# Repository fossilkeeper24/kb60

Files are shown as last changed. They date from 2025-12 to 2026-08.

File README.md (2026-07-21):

# kb60

> just another custom 60% keyboard

I didn't like having a numpad on my keyboard because it just collects dust as I never use the numpad. I also like having super easy to access media control. So I thought yeah why not let's make our own keyboard :3 While having the most minor changes to a 60% ISO layout keyboard, it's different enough to warrant its own project.

## Some pictures

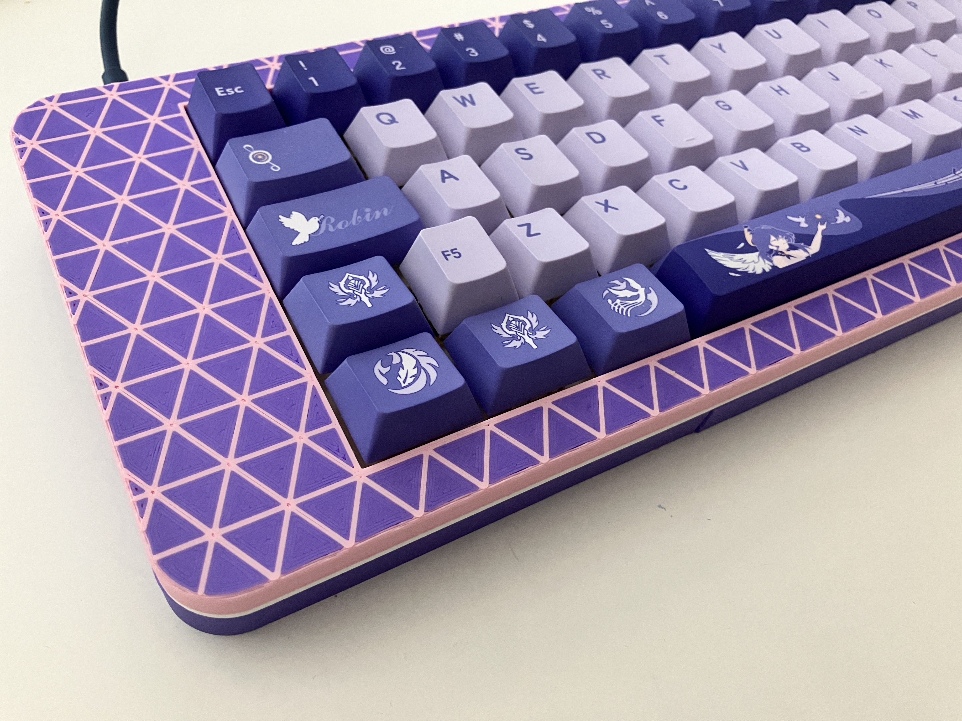
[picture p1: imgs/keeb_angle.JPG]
assembled keyboard


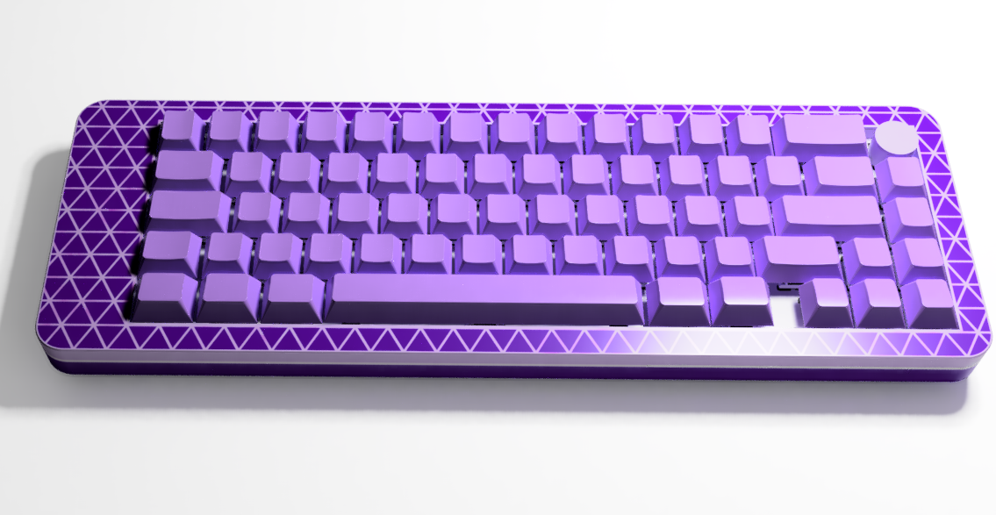
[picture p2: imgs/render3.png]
keyboard case render


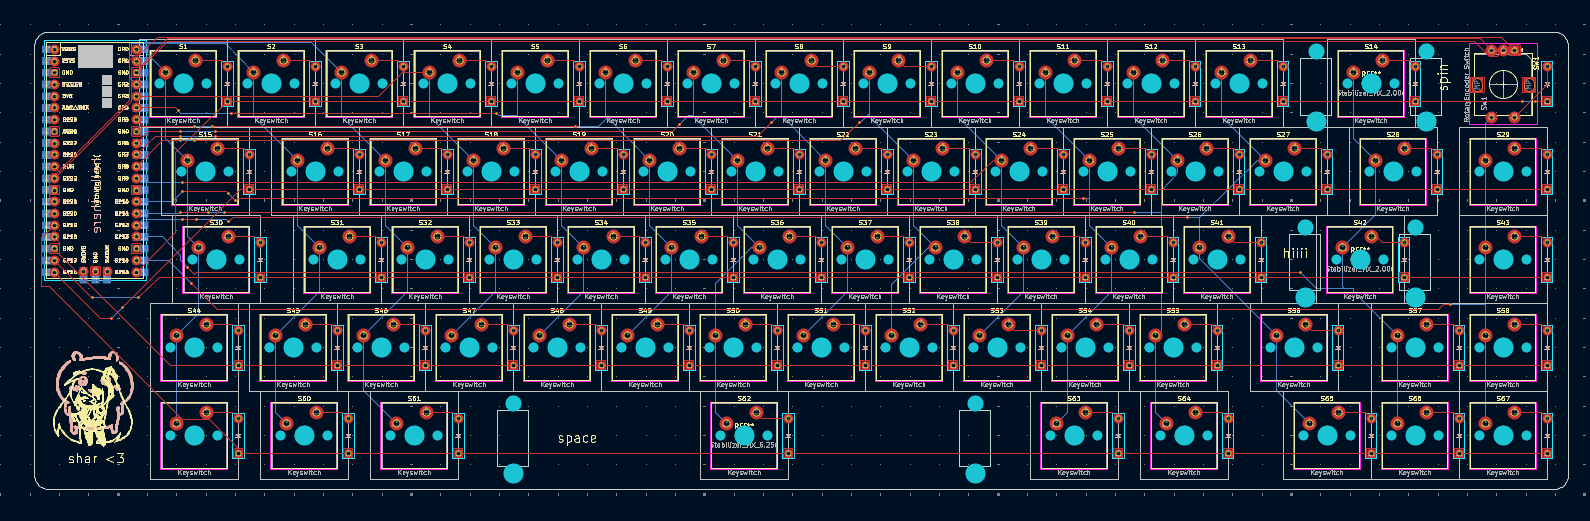
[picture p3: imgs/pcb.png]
pcb


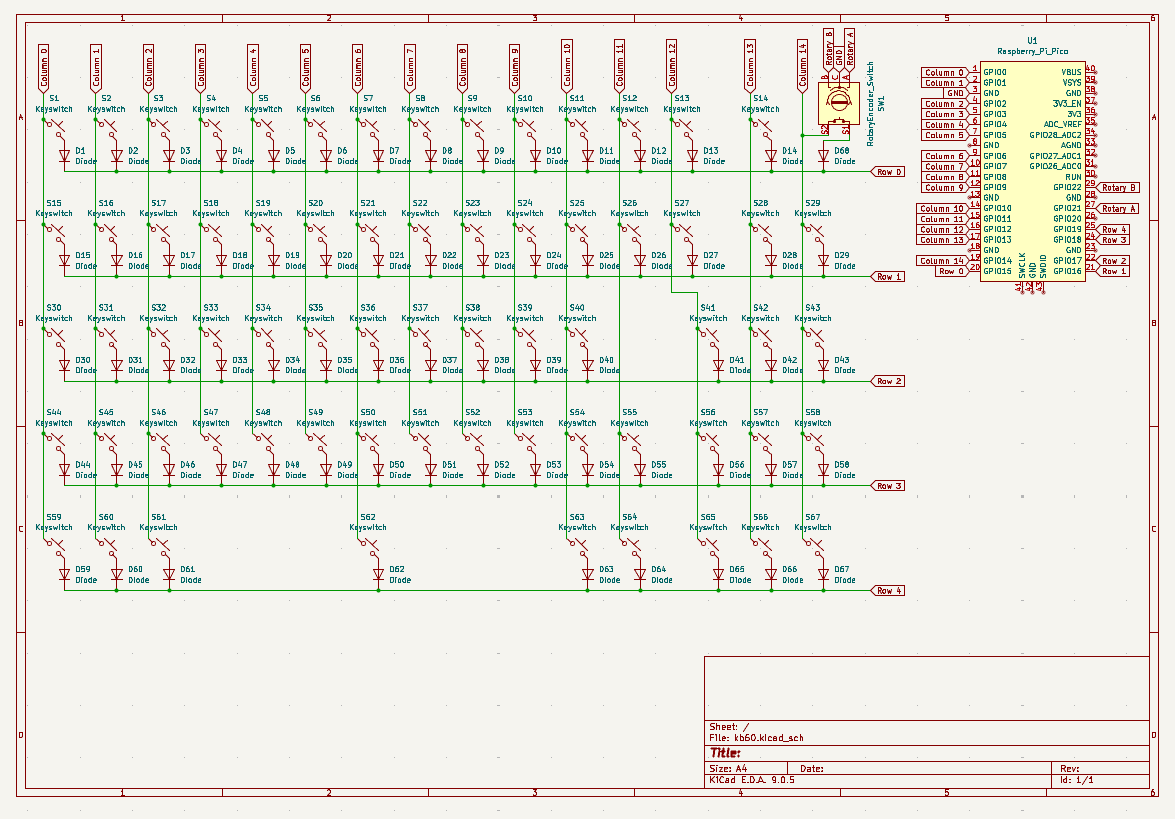
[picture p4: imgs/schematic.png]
schematic


## BOM

|Name |Link |price ($)|Notes |
|---|---|---|---|
|rasp pi pico  |https://www.aliexpress.com/item/1005003753933847.html |2.40 | |
|rotary encoder |https://www.aliexpress.com/item/1005005983134515.html |2.59 | 15mm length |
|stabilizers |https://www.aliexpress.com/item/1005001632672798.html |17.89 |choose ones that go with whatever switches i choose|
|switches |https://www.aliexpress.com/item/1005007665996795.html |14.68*2 | |
|diodes |https://www.aliexpress.com/item/2025724181.html|1.91 | |
|keycaps |https://www.aliexpress.com/item/1005008714429564.html |33.30 |142 keys |
|m3x12 screws  |https://www.aliexpress.com/item/32510989714.html |1.58 | |
|m3 heatset |https://www.aliexpress.com/item/1005006838108683.html |1.99 |L4 4.2mm |
|PLA |print legion goats | | |
|PCB |JLC PCB |31.85 |there are many coupons that i could use |
|TOTAL | |122.87 | |

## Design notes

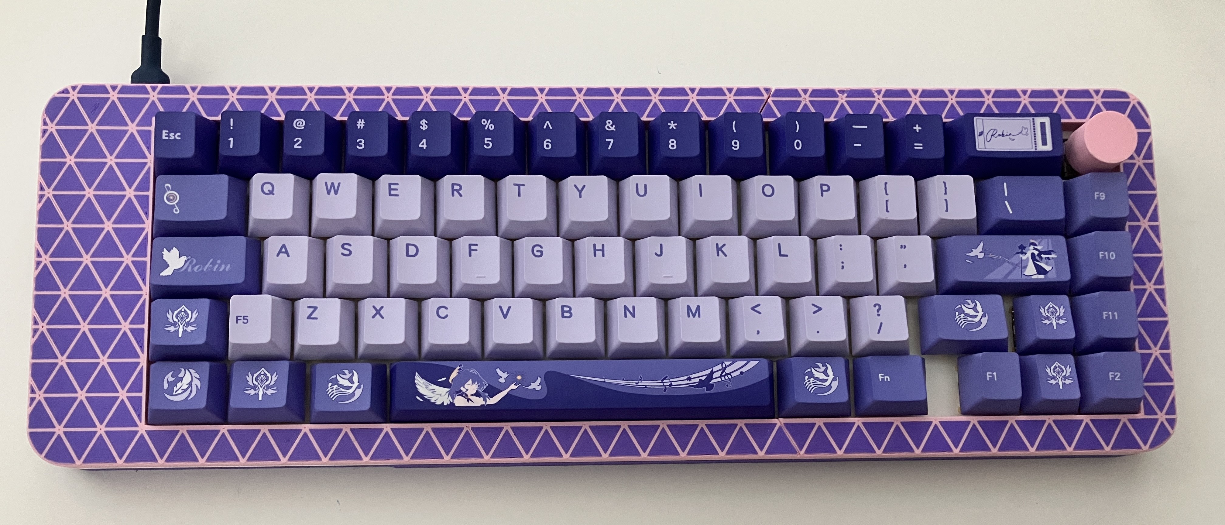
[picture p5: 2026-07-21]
imgs/keeb_topdown.JPG

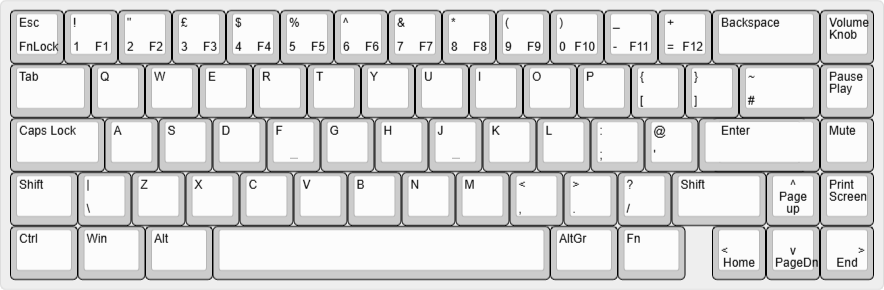
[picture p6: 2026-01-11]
imgs/keyboard-layout.png

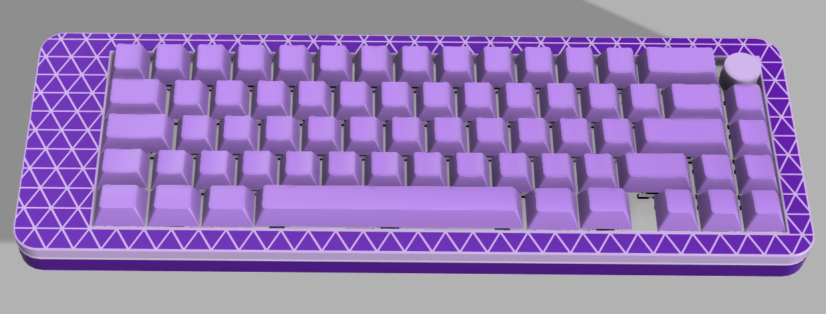
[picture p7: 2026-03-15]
imgs/plain view.png

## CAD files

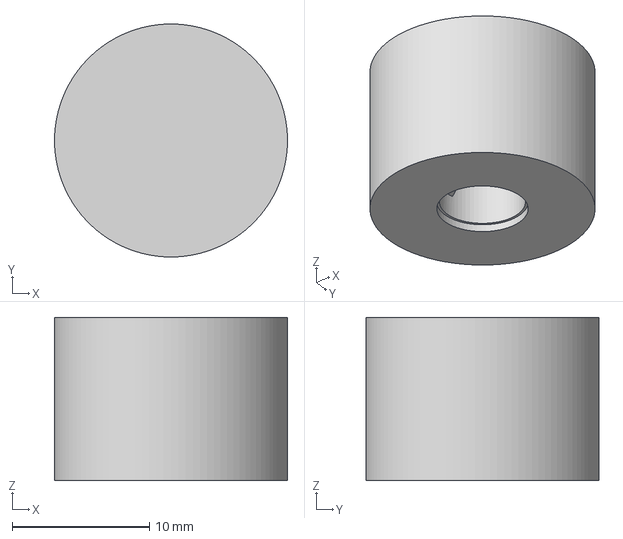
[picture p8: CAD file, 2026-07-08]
3d printttt/rotary encoder cap.3mf
17.0 x 17.0 x 11.9 mm

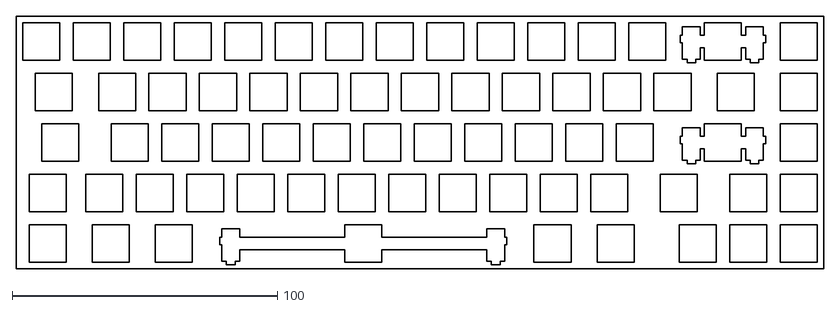
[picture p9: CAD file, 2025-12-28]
kb60 - fusion/plate2.dxf
304.8 x 95.2

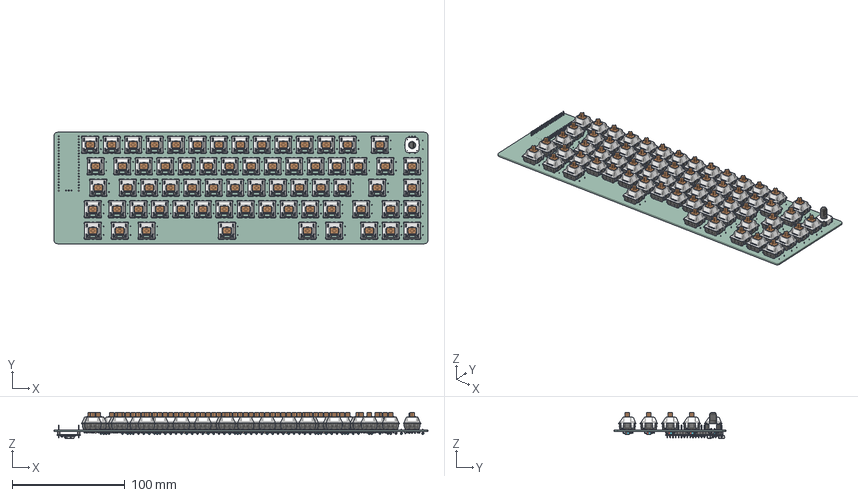
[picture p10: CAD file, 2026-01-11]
kb60 - kicad/kb60.step
332.0 x 99.0 x 23.3 mm
MX_PCB x 67
EC12 Encoder 10mm 3pin
Diode_DO-35 x 67
PinHeader_1x20_P2.54mm_Vertical.step
SMD Resistor, Configurable, Raspberry Pi Pico-R3_R7
U2, RT6150B-33GQW, Buck Boost Converter, Raspberry Pi Pico-R3
SMD Capacitor, Configurable, Raspberry Pi Pico-R3_C3
SMD Resistor, Configurable, Raspberry Pi Pico-R3_R14
SMD Capacitor, Configurable, Raspberry Pi Pico-R3_C12
SMD Resistor, Configurable, Raspberry Pi Pico-R3_R2
SMD Capacitor, Configurable, Raspberry Pi Pico-R3_C13
SMD Resistor, Configurable, Raspberry Pi Pico-R3_R12
U3, W25Q16JVUXIQ, Serial NOR Flash 16 Mbit, Raspberry Pi Pico-R3
SMD Resistor, Configurable, Raspberry Pi Pico-R3_R5
SMD Resistor, Configurable, Raspberry Pi Pico-R3_R1
MicroUSB Port, Raspberry Pi Pico-R3
X1, X12M000000S096, 12 Mhz Crystal Resonator, Raspberry Pi Pico-R3
SMD Capacitor, Configurable, Raspberry Pi Pico-R3_C2
SMD Resistor, Configurable, Raspberry Pi Pico-R3_R4
Q1, MOSFET, DMG1012T, Raspberry Pi Pico-R3
SMD Capacitor, Configurable, Raspberry Pi Pico-R3_C11
SMD Resistor, Configurable, Raspberry Pi Pico-R3_R6
RP2040 Microcontroller, Raspberry Pi Pico-R3
SMD Resistor, Configurable, Raspberry Pi Pico-R3_R9
D1, Diode, Schottky, Raspberry Pi Pico-R3
SMD Resistor, Configurable, Raspberry Pi Pico-R3_R3
SMD Capacitor, Configurable, Raspberry Pi Pico-R3_C8
SMD Capacitor, Configurable, Raspberry Pi Pico-R3_C6
SMD Capacitor, Configurable, Raspberry Pi Pico-R3_C17
SMD Capacitor, Configurable, Raspberry Pi Pico-R3_C16
SMD Capacitor, Configurable, Raspberry Pi Pico-R3_C7
SMD Resistor, Configurable, Raspberry Pi Pico-R3_R11
SMD Capacitor, Configurable, Raspberry Pi Pico-R3_C4
D2, QSME-C194, LED, Raspberry Pi Pico-R3
SMD Capacitor, Configurable, Raspberry Pi Pico-R3_C14
SMD Resistor, Configurable, Raspberry Pi Pico-R3_R8
SW1, Tact Switch, Raspberry Pi Pico-R3
SMD Capacitor, Configurable, Raspberry Pi Pico-R3_C9
SMD Resistor, Configurable, Raspberry Pi Pico-R3_R15
SMD Capacitor, Configurable, Raspberry Pi Pico-R3_C5
SMD Resistor, Configurable, Raspberry Pi Pico-R3_R13
SMD Resistor, Configurable, Raspberry Pi Pico-R3_R10
SMD Capacitor, Configurable, Raspberry Pi Pico-R3_C10
L1, Inductor, Raspberry Pi Pico-R3
PCB, Raspberry Pi Pico-R3
SMD Capacitor, Configurable, Raspberry Pi Pico-R3_C1
SMD Capacitor, Configurable, Raspberry Pi Pico-R3_C15
SMD Capacitor, Configurable, Raspberry Pi Pico-R3_C18
kb60_PCB

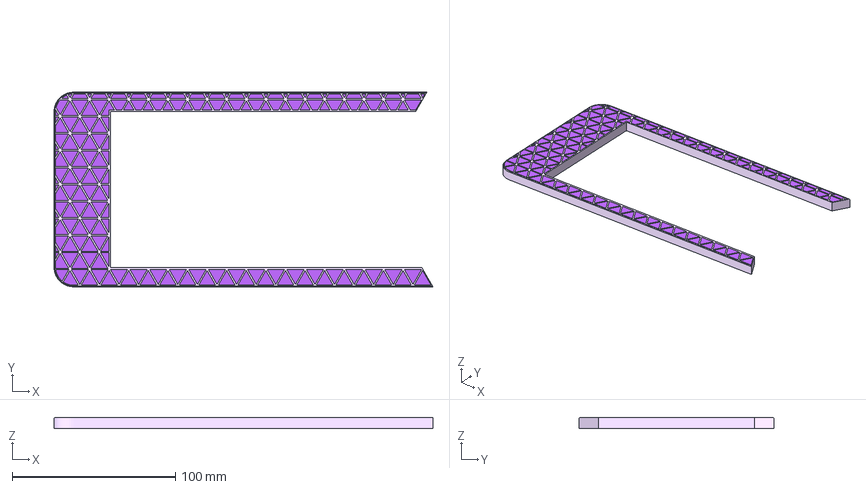
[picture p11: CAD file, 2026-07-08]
3d printttt/top left side.3mf
232.1 x 119.3 x 7.00 mm
bezel (1) (1) x 2
bezel (1) (10)
bezel (1) (100)
bezel (1) (101)
bezel (1) (102)
bezel (1) (103)
bezel (1) (104)
bezel (1) (105)
bezel (1) (106)
bezel (1) (107)
bezel (1) (108)
bezel (1) (109)
bezel (1) (110)
bezel (1) (111)
bezel (1) (112)
bezel (1) (113)
bezel (1) (114)
bezel (1) (115)
bezel (1) (116)
bezel (1) (117)
bezel (1) (118)
bezel (1) (119)
bezel (1) (12)
bezel (1) (120)
bezel (1) (121)
bezel (1) (122)
bezel (1) (123)
bezel (1) (124)
bezel (1) (125)
bezel (1) (126)
bezel (1) (127)
bezel (1) (128)
bezel (1) (129)
bezel (1) (13)
bezel (1) (130)
bezel (1) (131)
bezel (1) (132)
bezel (1) (133)
bezel (1) (134)
bezel (1) (135)
bezel (1) (136)
bezel (1) (137)
bezel (1) (138)
bezel (1) (139)
bezel (1) (14)
bezel (1) (140)
bezel (1) (141)
bezel (1) (142)
bezel (1) (143)
bezel (1) (144)
bezel (1) (145)
bezel (1) (146)
bezel (1) (147)
bezel (1) (148)
bezel (1) (149)
bezel (1) (15)
bezel (1) (150)
bezel (1) (151)
bezel (1) (152)
bezel (1) (153)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

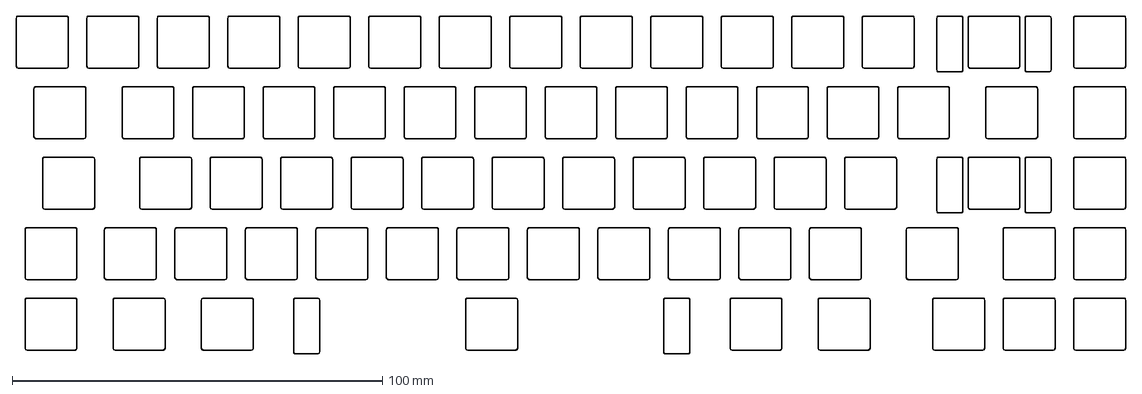
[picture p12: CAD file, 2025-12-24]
kb60 - fusion/kbplate.dxf
299.8 x 91.2 mm

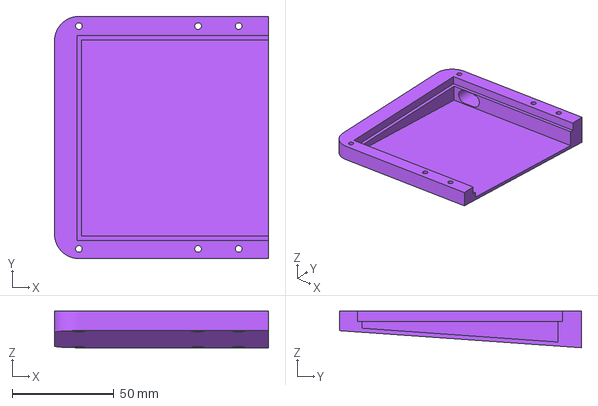
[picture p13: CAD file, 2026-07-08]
3d printttt/bottom left.3mf
105.4 x 119.3 x 18.0 mm

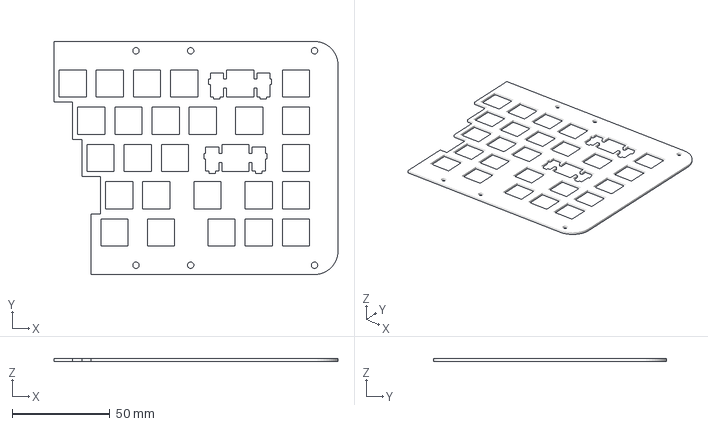
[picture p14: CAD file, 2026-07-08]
3d printttt/right plate.3mf
145.4 x 119.3 x 1.50 mm

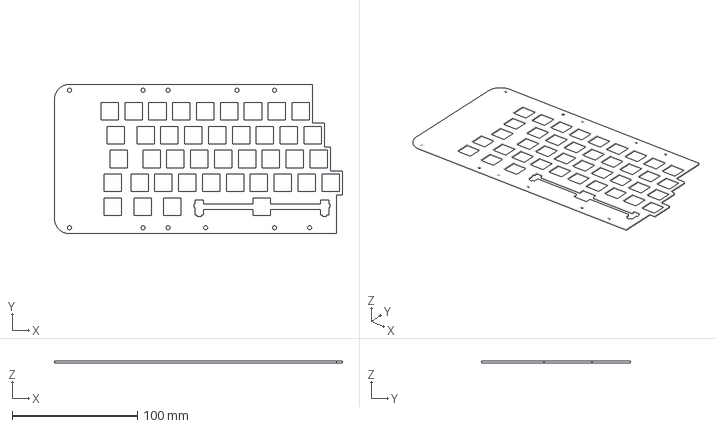
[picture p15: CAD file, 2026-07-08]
3d printttt/left plate.3mf
229.8 x 119.3 x 1.50 mm

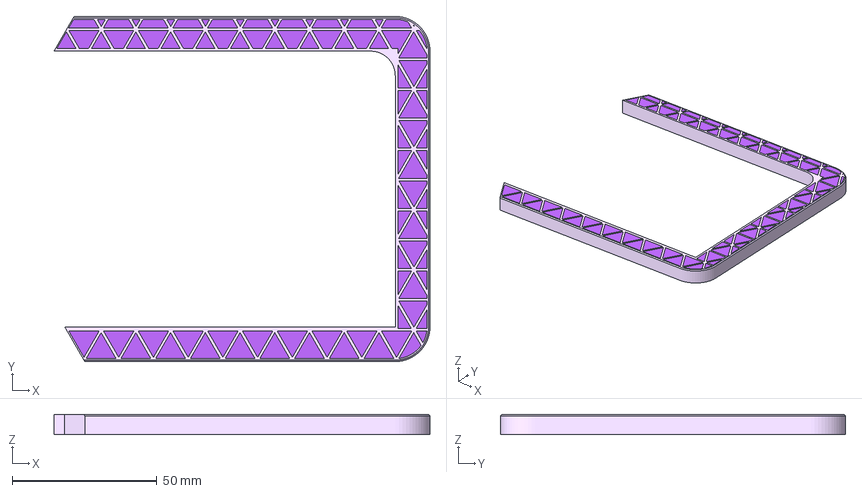
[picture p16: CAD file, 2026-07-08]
3d printttt/top right side.3mf
129.9 x 119.3 x 7.00 mm
bezel (1) (11)
bezel (1) (163)
bezel (1) (165)
bezel (1) (167)
bezel (1) (169)
bezel (1) (171)
bezel (1) (173)
bezel (1) (175)
bezel (1) (177)
bezel (1) (179)
bezel (1) (181)
bezel (1) (183)
bezel (1) (185)
bezel (1) (187)
bezel (1) (191)
bezel (1) (193)
bezel (1) (195)
bezel (1) (197)
bezel (1) (23)
bezel (1) (236)
bezel (1) (237)
bezel (1) (238)
bezel (1) (239)
bezel (1) (240)
bezel (1) (241)
bezel (1) (242)
bezel (1) (243)
bezel (1) (244)
bezel (1) (245)
bezel (1) (246)
bezel (1) (247)
bezel (1) (248)
bezel (1) (249)
bezel (1) (250)
bezel (1) (251)
bezel (1) (252)
bezel (1) (253)
bezel (1) (254)
bezel (1) (255)
bezel (1) (256)
bezel (1) (257)
bezel (1) (258)
bezel (1) (259)
bezel (1) (260)
bezel (1) (261)
bezel (1) (262)
bezel (1) (263)
bezel (1) (264)
bezel (1) (265)
bezel (1) (266)
bezel (1) (4)
bezel (1) (44)
bezel (1) (45)
bezel (1) (46)
bezel (1) (47)
bezel (1) (48)
bezel (1) (50)
bezel (1) (51)
bezel (1) (52)
bezel (1) (54)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

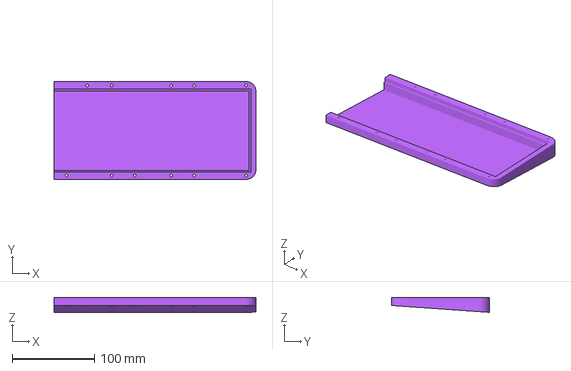
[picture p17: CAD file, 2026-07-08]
3d printttt/bottom right.3mf
246.0 x 119.3 x 18.0 mm

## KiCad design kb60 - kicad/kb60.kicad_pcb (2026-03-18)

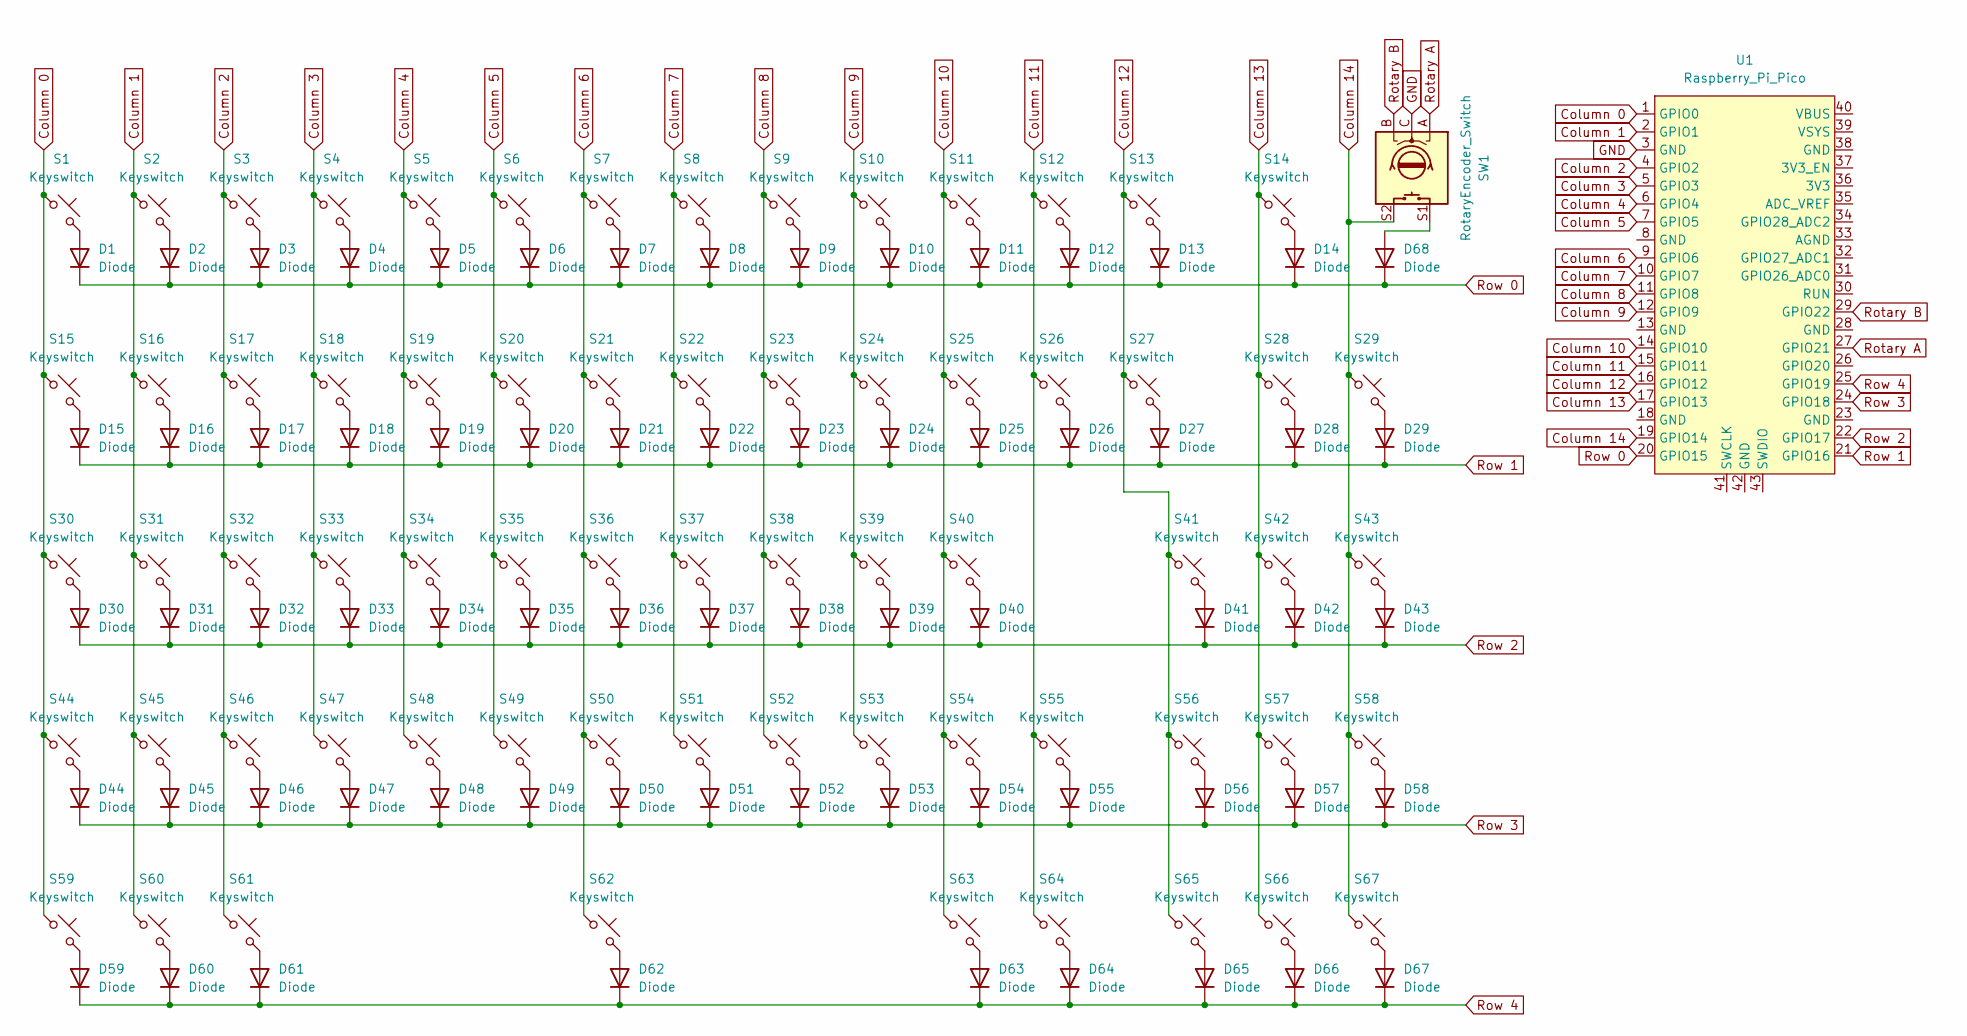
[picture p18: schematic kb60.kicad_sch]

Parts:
D1, D2, D3, D4, D5, D6, D7, D8, D9, D10, D11, D12, D13, D14, D15, D16, D17, D18, D19, D20, D21, D22, D23, D24, D25, D26, D27, D28, D29, D30, D31, D32, D33, D34, D35, D36, D37, D38, D39, D40, D41, D42, D43, D44, D45, D46, D47, D48, D49, D50, D51, D52, D53, D54, D55, D56, D57, D58, D59, D60, D61, D62, D63, D64, D65, D66, D67, D68: Diode; Diode_DO-35
S1, S2, S3, S4, S5, S6, S7, S8, S9, S10, S11, S12, S13, S14, S15, S16, S17, S18, S19, S20, S21, S22, S23, S24, S25, S26, S27, S28, S29, S30, S31, S32, S33, S34, S35, S36, S37, S38, S39, S40, S41, S42, S43, S44, S45, S46, S47, S48, S49, S50, S51, S52, S53, S54, S55, S56, S57, S58, S59, S60, S61, S62, S63, S64, S65, S66, S67: Keyswitch; MX_PCB_1.00u
SW1: RotaryEncoder_Switch; RotaryEncoder_Alps_EC12E-Switch_Vertical_H20mm
U1: Raspberry_Pi_Pico

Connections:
Column 0: S1.1, S15.1, S30.1, S44.1, S59.1, U1.1 (GPIO0)
Column 1: S2.1, S16.1, S31.1, S45.1, S60.1, U1.2 (GPIO1)
Column 2: S3.1, S17.1, S32.1, S46.1, S61.1, U1.4 (GPIO2)
Column 3: S4.1, S18.1, S33.1, S47.1, U1.5 (GPIO3)
Column 4: S5.1, S19.1, S34.1, S48.1, U1.6 (GPIO4)
Column 5: S6.1, S20.1, S35.1, S49.1, U1.7 (GPIO5)
Column 6: S7.1, S21.1, S36.1, S50.1, S62.1, U1.9 (GPIO6)
Column 7: S8.1, S22.1, S37.1, S51.1, U1.10 (GPIO7)
Column 8: S9.1, S23.1, S38.1, S52.1, U1.11 (GPIO8)
Column 9: S10.1, S24.1, S39.1, S53.1, U1.12 (GPIO9)
Column 10: S11.1, S25.1, S40.1, S54.1, S63.1, U1.14 (GPIO10)
Column 11: S12.1, S26.1, S55.1, S64.1, U1.15 (GPIO11)
Column 12: S13.1, S27.1, S41.1, S56.1, S65.1, U1.16 (GPIO12)
Column 13: S14.1, S28.1, S42.1, S57.1, S66.1, U1.17 (GPIO13)
Column 14: S29.1, S43.1, S58.1, S67.1, SW1.S2, U1.19 (GPIO14)
GND: SW1.C, U1.3 (GND)
unnamed: D1.2 (A), S1.2
unnamed: D2.2 (A), S2.2
unnamed: D3.2 (A), S3.2
unnamed: D4.2 (A), S4.2
unnamed: D5.2 (A), S5.2
unnamed: D6.2 (A), S6.2
unnamed: D7.2 (A), S7.2
unnamed: D8.2 (A), S8.2
unnamed: D9.2 (A), S9.2
unnamed: D10.2 (A), S10.2
unnamed: D11.2 (A), S11.2
unnamed: D12.2 (A), S12.2
unnamed: D13.2 (A), S13.2
unnamed: D14.2 (A), S14.2
unnamed: D15.2 (A), S15.2
unnamed: D16.2 (A), S16.2
unnamed: D17.2 (A), S17.2
unnamed: D18.2 (A), S18.2
unnamed: D19.2 (A), S19.2
unnamed: D20.2 (A), S20.2
unnamed: D21.2 (A), S21.2
unnamed: D22.2 (A), S22.2
unnamed: D23.2 (A), S23.2
unnamed: D24.2 (A), S24.2
unnamed: D25.2 (A), S25.2
unnamed: D26.2 (A), S26.2
unnamed: D27.2 (A), S27.2
unnamed: D28.2 (A), S28.2
unnamed: D29.2 (A), S29.2
unnamed: D30.2 (A), S30.2
unnamed: D31.2 (A), S31.2
unnamed: D32.2 (A), S32.2
unnamed: D33.2 (A), S33.2
unnamed: D34.2 (A), S34.2
unnamed: D35.2 (A), S35.2
unnamed: D36.2 (A), S36.2
unnamed: D37.2 (A), S37.2
unnamed: D38.2 (A), S38.2
unnamed: D39.2 (A), S39.2
unnamed: D40.2 (A), S40.2
unnamed: D41.2 (A), S41.2
unnamed: D42.2 (A), S42.2
unnamed: D43.2 (A), S43.2
unnamed: D44.2 (A), S44.2
unnamed: D45.2 (A), S45.2
unnamed: D46.2 (A), S46.2
unnamed: D47.2 (A), S47.2
unnamed: D48.2 (A), S48.2
unnamed: D49.2 (A), S49.2
unnamed: D50.2 (A), S50.2
unnamed: D51.2 (A), S51.2
unnamed: D52.2 (A), S52.2
unnamed: D53.2 (A), S53.2
unnamed: D54.2 (A), S54.2
unnamed: D55.2 (A), S55.2
unnamed: D56.2 (A), S56.2
unnamed: D57.2 (A), S57.2
unnamed: D58.2 (A), S58.2
unnamed: D59.2 (A), S59.2
unnamed: D60.2 (A), S60.2
unnamed: D61.2 (A), S61.2
unnamed: D62.2 (A), S62.2
unnamed: D63.2 (A), S63.2
unnamed: D64.2 (A), S64.2
unnamed: D65.2 (A), S65.2
unnamed: D66.2 (A), S66.2
unnamed: D67.2 (A), S67.2
unnamed: D68.2 (A), SW1.S1
Rotary A: SW1.A, U1.27 (GPIO21)
Rotary B: SW1.B, U1.29 (GPIO22)
Row 0: D1.1 (K), D2.1 (K), D3.1 (K), D4.1 (K), D5.1 (K), D6.1 (K), D7.1 (K), D8.1 (K), D9.1 (K), D10.1 (K), D11.1 (K), D12.1 (K), D13.1 (K), D14.1 (K), D68.1 (K), U1.20 (GPIO15)
Row 1: D15.1 (K), D16.1 (K), D17.1 (K), D18.1 (K), D19.1 (K), D20.1 (K), D21.1 (K), D22.1 (K), D23.1 (K), D24.1 (K), D25.1 (K), D26.1 (K), D27.1 (K), D28.1 (K), D29.1 (K), U1.21 (GPIO16)
Row 2: D30.1 (K), D31.1 (K), D32.1 (K), D33.1 (K), D34.1 (K), D35.1 (K), D36.1 (K), D37.1 (K), D38.1 (K), D39.1 (K), D40.1 (K), D41.1 (K), D42.1 (K), D43.1 (K), U1.22 (GPIO17)
Row 3: D44.1 (K), D45.1 (K), D46.1 (K), D47.1 (K), D48.1 (K), D49.1 (K), D50.1 (K), D51.1 (K), D52.1 (K), D53.1 (K), D54.1 (K), D55.1 (K), D56.1 (K), D57.1 (K), D58.1 (K), U1.24 (GPIO18)
Row 4: D59.1 (K), D60.1 (K), D61.1 (K), D62.1 (K), D63.1 (K), D64.1 (K), D65.1 (K), D66.1 (K), D67.1 (K), U1.25 (GPIO19)

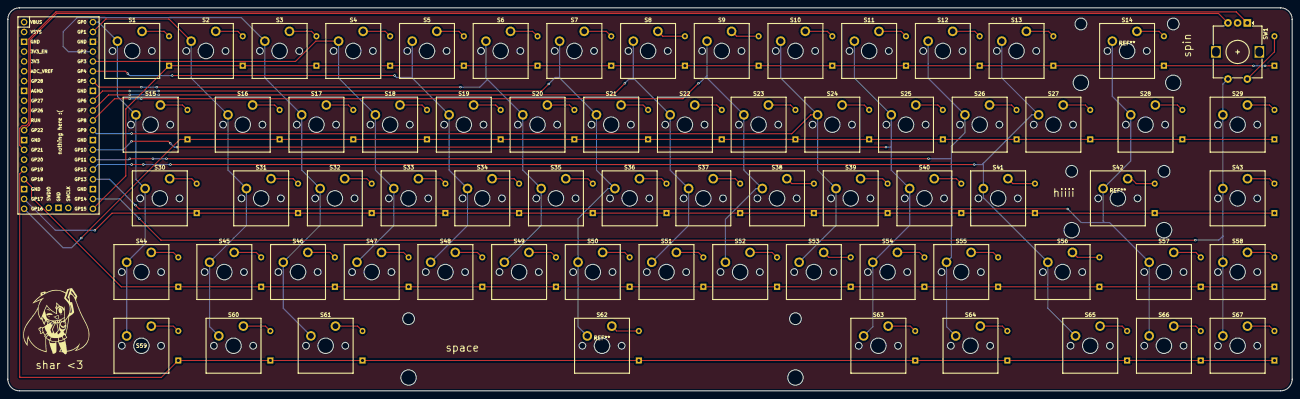
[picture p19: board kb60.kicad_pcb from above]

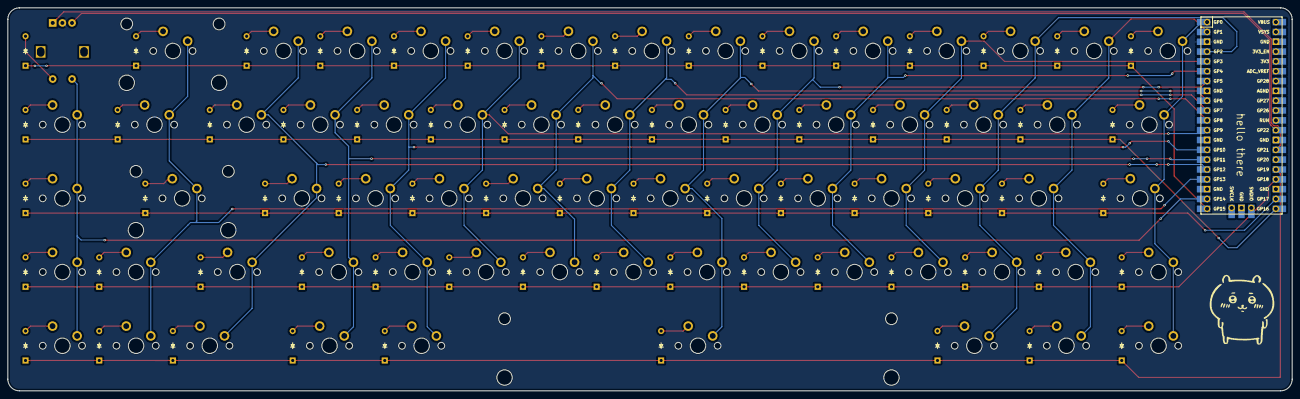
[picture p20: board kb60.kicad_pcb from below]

Board: 2 copper layers, 332.0 x 99.0 mm, 137 parts (69 on the bottom side), 91 nets.

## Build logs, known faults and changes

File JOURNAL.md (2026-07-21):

<!--
  This journal is auto generated by Hack Club Blueprint.
-->

# 11/2/2025 - Planned keyboard layout  

_Time spent: 0.6h_  

I made a plan for what I want the layout of my keyboard to look like:



It looks super close to the ANSI layout because it sort of is but it's still the slightest bit different.
For example, the (@) symbol and (") symbol are where they would be in ISO UK layout. 
And then instead of having the page up/down keys on the right side I have media control.
I just based it off of what I normally use the most.
I also would put volume knob in the corner but I wasn't sure exactly how to show that in keyboard-layout-editor.com so it's just shown as an average key.  

# 11/21/2025 - Made switch matrix for pcb schematic  

_Time spent: 1.6h_  

The most tangible thing I made progress with was the pcb schematic. I made the switch matrix for the keys.



Before that, I did some searching around the internet, trying to find which microcontroller is best for a keyboard, and would suit my current level of expertise. I didn't want one that would give me more work than necessary, like for example one that uses BLE, so I settled with the Raspberry Pi Pico. I have seen it used in several keyboards due to its number of I/O pins.
At first I was trying to find a module that had a usb-c port built into it before realising after too long that I could just get a different cable specially for the pi pico and it wouldn't be too much of an inconvenience. I decided that that was better than taking a gamble with some microcontroller that I don't know about nor can find resources for.  

# 11/29/2025 - placed switches in rough place on pcb  

_Time spent: 2.7h_  

### Found the rotary encoder I wanted
I wanted to use a rotary encoder as a volume control. I decided to use the [Alps EC12](https://www.aliexpress.com/item/1005005196870256.html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) as I believe it is referred to as.

### Finished the schematic

I almost forgot to add the rotary encoder before moving on to the PCB, so this was a clutch. Definitely saved me some future sorrow.

### Started PCB
I have placed the switches in the rough area of where I would want them to be placed in the PCB.

I am still to match them with the layout of the keyboard, and am yet to place the diodes in the right places.

# 12/2/2025 - Finished placing components on PCB  

_Time spent: 2.9h_  

I followed my plan for my keyboard layout to place the footprints of the switches on the PCB. It was very finicky trying to figure out how much room I should leave in between each switch so that their corresponding keycaps have enough space. 


I also added the rotary encoder into the switch matrix as it has a switch functionality.


# 12/17/2025 - Routed the switch matrix  

_Time spent: 0.3h_  

First I removed the border of the PCB because I figured it would be better to add that in after I've routed everything.
I have now routed the rows and columns of the switch matrix.



# 12/23/2025 - Finished routing PCB  

_Time spent: 2.0h_  

I finished routing the pico to all the other components.
It was a little difficult to guage how many vias are too many and where I should place them. Finding the balance between keeping the traces as short as possible and having the minimum number of vias. I do not know what the standard for that is but I did what I could.

## The finished PCB



# 12/24/2025 - Added sketch of plate to fusion  

_Time spent: 0.4h_  

I used a plate generator to generate a sketch for my plate and imported that into fusion.



I also added a ground fill to my PCB. 


Before doing so a read plenty of forums to understand the importance of ground planes to prevent RF interference.  

# 12/28/2025 12 PM - made majority of the cad for the case  

_Time spent: 7.0h_  

I imported my pcb model from kicad into fusion and using that, i made the sketch of the dimensions that I would need for the plate and case of the keyboard.


made the case and plate. I made it have an angle because ergonomics and it would otherwise be too tall due to my placement of the pi pico.


While I was adding the m3 screws, I realised that they were strangely close to the front of my pcb compared to the back


This is because I made the front of my pcb unnecessarily large in kicad. This was a quick enough fix.


# 12/28/2025 5 PM - finished cad for case and plate  

_Time spent: 1.0h_  

I added a pattern to my case and changed up the appearance


The way I went about sketching the pattern was less than ideal because I manually drew in 2 triangles and made the pattern about the 2 instead of just manipulating one triangle. Hence, the pattern isn't quite perfect but it is good enough for now. If I later have the time, I would go in and change it up so that it is a little more pleasing.  

# 12/28/2025 10 PM - started qmk firmware  

_Time spent: 1.5h_  

I got started with using qmk to make the firmware for my keyboard. It was my first time using it so reading the docs was getting a lot of information all at once. However, I have downloaded all the prerequisites and have begun to make the changes that I need to make on the config files. I started with the GPIO pins that will be used for the rows and columns of the switch matrix.


I also started to annotate the png of my keyboard layout as it would be a helpful when editing the config for each of the keys
keyboard-layout

# 1/17/2026 - switched to kmk + added a layer  

_Time spent: 2.0h_  

I decided that qmk was too complicated for my goal so I switched to using kmk for my firmware. The kmk docs were much easier to understand and follow. It was a good decision.

I took the keymap that I had written for qmk and just tweaked it a little.
I then added a base and function layer.



This may well be all the firmware that the keyboard needs to function.  

# 3/11/2026 - A few polishing tasks  

_Time spent: 2.0h_  

I filled out the BOM in a google sheets spreadsheet, except the price for the PCB.


This included looking for the keycaps that I thought would look best. 

I chose this set as I believe the colour scheme is cohesive with the colour scheme that I have designed for my keyboard case.

I also modelled a cap for the rotary encoder that I would be using.



# 3/14/2026 - cleaned up my readme  

_Time spent: 0.5h_  

I added the fusion files to my github repo and added some more information to the README. I added the BOM and some pictures for each part of the project


# 3/15/2026 - fixed errors that my friend found  

_Time spent: 1.2h_  

I added footprints for stabilizers since I hadn't already and I had chosen to use plate mounted stabilizers.


Previously, I did not have and tolerance in my case for where my PCB is supposed to sit so I added some, and also a shelf for it to sit on. I split the case up so that it would be a better size to 3d print and added some extra screws.



Finally, I added some keycaps in the model so that it can be visualized easier.

# 7/21/2026 - Built the keyboard irl!  

_Time spent: 10.0h_  

I have soldered and assembled my keyboard! It is now in use and sounds great. I had some trouble with the firmware but it was nothing that a bit of experimenting couldn't fix. Designing and building this keyboard was such a fun learning experience.
keeb_topdown

I may have used some function keys for some keys that the keycap set was short of but who's looking that hard anyway...

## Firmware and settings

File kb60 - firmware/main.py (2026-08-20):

print("Starting")

import board

from kmk.kmk_keyboard import KMKKeyboard
from kmk.keys import KC
from kmk.scanners import DiodeOrientation

from kmk.extensions.international import International

from kmk.modules.layers import Layers

from kmk.modules.holdtap import HoldTap

from kmk.extensions.media_keys import MediaKeys

from kmk.modules.encoder import EncoderHandler
encoder_handler = EncoderHandler()

keyboard = KMKKeyboard()

keyboard.col_pins = (board.GP0, board.GP1, board.GP2, board.GP3, board.GP4, board.GP5, board.GP6, board.GP7, board.GP8, board.GP9, board.GP10, board.GP11, board.GP12, board.GP13, board.GP14,)
keyboard.row_pins = (board.GP15, board.GP16, board.GP17, board.GP18, board.GP19,)
keyboard.diode_orientation = DiodeOrientation.ROW2COL

keyboard.extensions.append(International())
keyboard.modules.append(Layers())
keyboard.extensions.append(MediaKeys())
keyboard.modules = [Layers(), HoldTap(), encoder_handler]

TRANS = KC.TRNS
xxxxxxx = KC.NO
RAISE = KC.TT(1)

keyboard.keymap = [
    [ #LAYER 0: BASE
        KC.ESC, KC.N1,    KC.N2,    KC.N3,    KC.N4,    KC.N5,    KC.N6,    KC.N7,    KC.N8,    KC.N9,    KC.N0,    KC.MINS, KC.EQL,  KC.BSPC, KC.MUTE, 
        KC.TAB,  KC.Q,    KC.W,    KC.E,    KC.R,    KC.T,    KC.Y,    KC.U,    KC.I,    KC.O,    KC.P,    KC.LBRC, KC.RBRC, KC.NUHS, KC.MPLY,
        KC.CAPS, KC.A,    KC.S,    KC.D,    KC.F,    KC.G,    KC.H,    KC.J,    KC.K,    KC.L,    KC.SCLN, KC.NO,   KC.QUOT, KC.ENT,  KC.MUTE,
        KC.LSFT, KC.NUBS, KC.Z,    KC.X,    KC.C,    KC.V,    KC.B,    KC.N,    KC.M,    KC.COMM, KC.DOT,  KC.SLSH, KC.RSFT, KC.UP,   KC.PSCR,
        KC.LCTL, KC.LGUI, KC.LALT, KC.NO,   KC.NO,   KC.NO,   KC.SPC,   KC.NO,  KC.NO,   KC.NO,   KC.RALT, RAISE,   KC.LEFT, KC.DOWN, KC.RGHT,
        ],
        [ #LAYER 1: FN
        KC.ESC, KC.F1,   KC.F2,   KC.F3,   KC.F4,   KC.F5,   KC.F6,   KC.F7,   KC.F8,   KC.F9,   KC.F10,  KC.F11,  KC.F12,    KC.DELETE, KC.GRV,
        TRANS,   TRANS,   TRANS,   TRANS,   TRANS,   TRANS,   TRANS,   TRANS,   TRANS,   TRANS,   TRANS,   TRANS,   TRANS,     TRANS,     TRANS,
        TRANS,   TRANS,   TRANS,   TRANS,   TRANS,   TRANS,   TRANS,   TRANS,   TRANS,   TRANS,   TRANS,   KC.NO,   TRANS,     TRANS,     TRANS,
        TRANS,   TRANS,   TRANS,   TRANS,   TRANS,   TRANS,   TRANS,   TRANS,   TRANS,   TRANS,   TRANS,   TRANS,   TRANS,     KC.PGUP,   TRANS,
        TRANS,   TRANS,   TRANS,   KC.NO,   KC.NO,   KC.NO,   TRANS,   KC.NO,   KC.NO,   KC.NO,   TRANS,   TRANS,   KC.HOME,   KC.PGDN,   KC.END,
        ]
]

encoder_handler.divisor = 2
encoder_handler.pins = ((board.GP21, board.GP22, None,), )

encoder_handler.map = [ (( KC.VOLU, KC.VOLD,),), # Layer 0
                        (( KC.BRIU, KC.BRID,),), ] # Layer 1

if __name__ == '__main__':
    keyboard.go()

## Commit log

2025-11-11 initialise project
    [kb60.kicad_pcb, kb60.kicad_sch]
2025-11-11 Delete OPL Kicad library
    I dont need it
2025-11-23 made schematic for led matrix
    also imported scottokeebs library
    [kb60.kicad_sch]
2025-11-29 completed schematic
    [kb60.kicad_pcb, kb60.kicad_sch]
2025-11-29 started pcb design
    placed keys in rough places
    [kb60.kicad_pcb, kb60.kicad_sch]
2025-12-02 added rotary encoder to switch matrix
    as it has a switch as well
    also added my keyboard layout that i wanted as a guideline for pcb placement
    [kb60.kicad_pcb, kb60.kicad_sch]
2025-12-02 pcb layout mostly done and 3d models added
    [kb60.kicad_pcb]
2025-12-02 finished pcb placements
    [kb60.kicad_pcb]
2025-12-23 finished routing pcb
    [kb60.kicad_pcb]
2025-12-24 added ground fill and prod files
    [kb60.kicad_pcb]
2025-12-24 added plate dxf file
    from plate generator
    [kbplate.dxf]
2025-12-28 made the pcb a lil smaller
    and moved some components
    [kb60.kicad_pcb, kb60.step, plate2.dxf]
2026-01-11 upload kmk files
    [kb60.kicad_pcb, kb60.step]
2026-03-12 Added BOM
2026-03-14 added the fusion cad
2026-03-14 add bom.csv
    [bom.csv]
2026-03-14 add stabilizers to pcb
    [kb60.kicad_pcb]
2026-03-15 fixed cad errors
    added tolerance to where the pcb goes. split the case so that it is easier to print. fixed alignment errors
2026-03-16 centered pcb in kicad
    [kb60.kicad_pcb]
2026-03-17 changed link to diodes
    because original link is no longer available
2026-03-17 replaced pcb pic with updated ver
2026-03-17 update bom links
2026-03-17 made bom notes more specific
2026-03-17 fix bom prices
2026-03-18 removed 90 degree traces
    was given feedback to as it is not best practice
    [kb60.kicad_pcb]
2026-07-08 fixed firmware + added 3mfs for 3d printing
    [bottom left.3mf, bottom right.3mf, left plate.3mf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]
2026-07-21 added img of assembled keeb to read me
2026-08-20 tweak firmware
    rotary encoder directions
